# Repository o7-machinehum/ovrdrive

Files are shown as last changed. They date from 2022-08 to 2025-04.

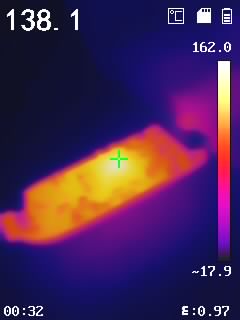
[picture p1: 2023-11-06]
testing/thermal/19700101/IMG000017.jpeg

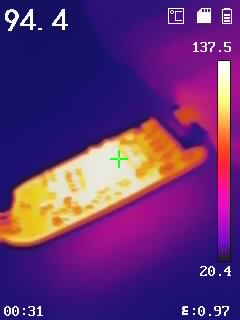
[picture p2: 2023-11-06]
testing/thermal/19700101/IMG000016.jpeg

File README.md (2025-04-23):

# Ovrdrive


Ovrdrive is a purpose built security focused usb drive. If the user doesn't plug it in three times rapidly, the drive it will appear completely blank. It is entirely open source and all the tools used to build it are open source. 

## Getting this Code
I've added quite a bit of git lfs content, I will eventually remove all this, but for now you probably don't want to check this out. You can do so like this

    GIT_LFS_SKIP_SMUDGE=1 git clone git@github.com:o7-machinehum/ovrdrive.git

## Content
 - [Blog Post](https://interruptlabs.ca/2022/07/29/I-m-Building-a-Self-Destructing-USB-Drive/)
 - [YouTube Content](https://youtu.be/Wrcy6ySjSu8)
 - [Buy in my Shop](https://shop.rootkitlabs.com/products/ovrdrive-usb)

## Firmware
```
cd fw
make deploy
```

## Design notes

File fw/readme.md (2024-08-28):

# Overdrive Firmware
The firmware consists of just one source file and a header `ovrdrive.c` and `ovrdrive.h`. The hardware is an ATmega25 programmed from a TC2030 programming pad (J3). I have tested that it's possible to use a 1mm pitch, 2x3 header by just holding it down to the pads for a quick and dirty program.

## Software Requirements
```
make
avr-gcc
avrdude
```

## Building
```
make
```

## Flashing
To flash you need an AVR ISP programmer (or an Arduino in ISP mode). 
```
make fuse
make flash
```
In the `rel` folder you will find the `ovrdrive_r1.elf` which is the firmware that was shipped with the device. You can flash this with the `make deploy`

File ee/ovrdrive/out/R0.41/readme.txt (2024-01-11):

Ovrdrive
--------
Size :	36.6 x 15 mm
Layer : 4 Layers
Material : FR-4: TG150
Thickness : 0.6 mm
Min track/spacing : 4/4mil
Min hole size : 0.2mm
Solder mask : Black
Silkscreen : White
Edge connector : No
Surface finish : HASL lead free
Via process : Tenting vias
Finished copper : 1 oz Cu (Inner Copper:1 oz)
Remove product No. : Yes

Update From R0.4
----------------
1) Changed board outline to be more snug in enclosure
2) Added CE logo
3) C3/C14 -> 1uF to 10uF
    - Shouldn't have to plug in / out as fast
4) R5 -> 22R to 0R
    - For heating up better

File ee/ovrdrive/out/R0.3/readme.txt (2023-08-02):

Ovrdrive
--------

Thickness : 0.6 mm
Min hole size : 0.2mm

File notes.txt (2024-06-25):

# Notes

# Final TODO
    - [ ] Extend board for a nicer fit
    - [ ] Increase charge caps capacitance
    - [ ] Replace programming port with TC2030

# Boards (V2)
    1) Hacked to try to make flash work. Probably NFG.
    2) Replaced flash to K9GAG08U0E. Removed: Q2 and C1. Not enumerating through dmesg.
    3) Populated with MT29F64G08CBABAWP
        - Works!
    4-7) Not touched
    8) Poached IC
    9) Not touched
    10) Sent to Crowdsupply

# Boards (V3)
    1) Replaced IC to SM3257ENQBA. Works! Accidentally wired flash backwards.
        - Used SM3257ENBA-P0816
    2) "Bad Block over setting 0X11"
        - No diodes!
        - Trying Star_SM3257ENAA_SM3261AB_M0531
        - Worked (with SM3257ENAA) This IC is okay!
    3) Not showing up
        - Different flash (didn't have enough)
    4) Not showing up - Gets hot
    5) Worked with Star_SM3257ENAA_SM3261AB_M0531

# Boards (V4)
    - ** Important ** : Make sure Virtualbox USB is set to USB 1.1
    - Used SM3257ENBA-P0816
        - Previsioned all 20, no visible errors.

## Parts
  - ATTINY24A-CCUR  - BGA version
  - ATTINY24-20PU   - DIP version
  - K9gag08u0e-Scb0 - NAND Flash
  - SM3255AA        - What dmesg thinks the chip is
  - SM3257EN        - Part number on the chip
  - SM3257ENAA      - Reported by SMI Mass Production Tool
  - 838-22-004-10-001101

## Notes
```
[machinehum@whitebox Star_SM3257ENAA_N0726]$ find . -iname "SM3257ENAA*.FFW"
./UFD_ALL_ForceFW/SM3257ENAA.FFW
```
This is the "ISP" or firmware, source: https://www.usbdev.ru/articles/a_smi/ispcantbefound/

## SMI Mass QC tool
Settings Password: 320
Debug Password: 1111

## Links and Notes
  - [Russian Site 1](https://www.usbdev.ru/articles/testmod/)
  - [Russian Site 2](https://www.usbdev.ru/files/smi/)
  - [SMI MP Tool](https://www.usbdev.ru/files/smi/smimptool/)
  - [Notes on Flash](https://www.elinfor.com/knowledge/practical-guide-for-flash-memory-p-10889)
  - [SMI MP Tool 2](https://flashboot.ru/files/file/243/)
  - [ST's Part](https://www.st.com/en/microcontrollers-microprocessors/st72681.html)

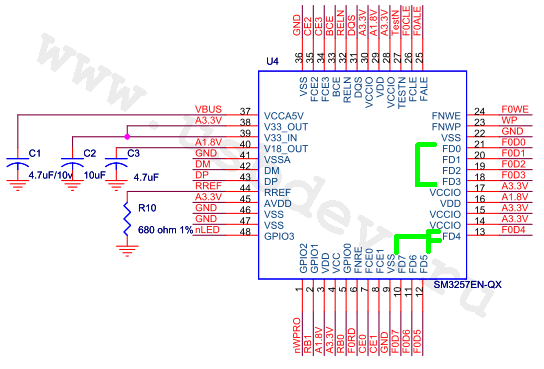
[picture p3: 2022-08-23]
ee/datasheets/SM3257-design.gif

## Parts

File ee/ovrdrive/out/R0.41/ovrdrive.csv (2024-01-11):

Source: | /Users/machinehum/projects/ovrdrive/ee/ovrdrive/ovrdrive.kicad_sch
Date: | 2024 January 11, Thursday 13:58:31
Tool: | Eeschema 7.0.7
Generator: | /opt/homebrew/bin/kicad-vault
Component Count: | 39
Ref | Qnty | Value | Footprint | Part Number | Detailed Description
C1, C15, C16, C18, | 4 | 100nF | Capacitor_SMD:C_0603_1608Metric | CC0603KRX7R7BB104 | 0.1 µF ±10% 16V Ceramic Capacitor X7R 0603 (1608 Metric)
C2, C4, C8, C9, C10, C11, C12, C13, C17, | 9 | 1uF | Capacitor_SMD:C_0603_1608Metric | CC0603KRX7R7BB105 | 1 µF ±10% 16V Ceramic Capacitor X7R 0603 (1608 Metric)
C3, C14, | 2 | 10uF | Capacitor_SMD:C_0603_1608Metric | CL10A106MQ8NNNC | 10 µF ±20% 6.3V Ceramic Capacitor X5R 0603 (1608 Metric)
C5, C6, C7, | 3 | 4.7uF | Capacitor_SMD:C_0603_1608Metric | CL10A475KP8NNNC | 4.7 µF ±10% 10V Ceramic Capacitor X5R 0603 (1608 Metric)
D1, | 1 | LED | LED_SMD:LED_0603_1608Metric | XZMG53W-1 | Green 568nm LED Indication - Discrete 2.2V 0603 (1608 Metric)
D2, D3, | 2 | BAS70LP-7B | Diode_SMD:D_0402_1005Metric | BAS70LP-7B | Diode 70 V 70mA Surface Mount X1-DFN1006-2
J1, | 1 | USB_A | Connector_USB:USB_A_CNCTech_1001-011-01101_Horizontal | 480372200 | USB-A (USB TYPE-A) USB 2.0 Plug Connector 4 Position Surface Mount, Right Angle; Through Hole
R1, R2, | 2 | 1M | Resistor_SMD:R_0402_1005Metric | RC0402FR-071ML | 1 MOhms ±1% 0.063W, 1/16W Chip Resistor 0402 (1005 Metric) Moisture Resistant Thick Film
R3, R4, | 2 | 2.2R | Resistor_SMD:R_0603_1608Metric | RC0603FR-072R2L | 2.2 Ohms ±1% 0.1W, 1/10W Chip Resistor 0603 (1608 Metric) Moisture Resistant Thick Film
R5, | 1 | 0R | Resistor_SMD:R_0603_1608Metric | RC0603FR-070RL | 0 Ohms Jumper Chip Resistor 0603 (1608 Metric) Moisture Resistant Thick Film
R6, | 1 | 1k | Resistor_SMD:R_0603_1608Metric | RC0603FR-071KL | 1 kOhms ±1% 0.1W, 1/10W Chip Resistor 0603 (1608 Metric) Moisture Resistant Thick Film
R7, R8, | 2 | 10k | Resistor_SMD:R_0402_1005Metric | RC0402FR-0710KL | 10 kOhms ±1% 0.063W, 1/16W Chip Resistor 0402 (1005 Metric) Moisture Resistant Thick Film
R9, | 1 | 1k | Resistor_SMD:R_0402_1005Metric | RC0402FR-071KL | 1 kOhms ±1% 0.063W, 1/16W Chip Resistor 0402 (1005 Metric) Moisture Resistant Thick Film
R10, | 1 | 680R | Resistor_SMD:R_0603_1608Metric | RC0603FR-07680RL | 680 Ohms ±1% 0.1W, 1/10W Chip Resistor 0603 (1608 Metric) Moisture Resistant Thick Film
R14, R15, | 2 | 10k | Resistor_SMD:R_0603_1608Metric | RC0402FR-0710KL | 10 kOhms ±1% 0.063W, 1/16W Chip Resistor 0402 (1005 Metric) Moisture Resistant Thick Film
U1, | 1 | SM3257ENT | Package_QFP:TQFP-48_7x7mm_P0.5mm | SM3257ENAA
U2, | 1 | FLASH | TSOP48:tsop48 | MT29F64G08CBABAWP
U3, | 1 | ATtiny24A-MM | Package_DFN_QFN:QFN-20-1EP_3x3mm_P0.45mm_EP1.6x1.6mm | ATTINY24A-MMHR | AVR AVR® ATtiny Microcontroller IC 8-Bit 20MHz 2KB (1K x 16) FLASH 20-VQFN (3x3)
U4, | 1 | SN74LVC1G32DCKR | Package_TO_SOT_SMD:SOT-353_SC-70-5 | SN74LVC1G32DCKR | OR Gate IC 1 Channel SC-70-5
U5, | 1 | DRV8837C | Package_SON:WSON-8-1EP_2x2mm_P0.5mm_EP0.9x1.6mm | DRV8837CDSGR | Motor Driver NMOS PWM 8-WSON (2x2)

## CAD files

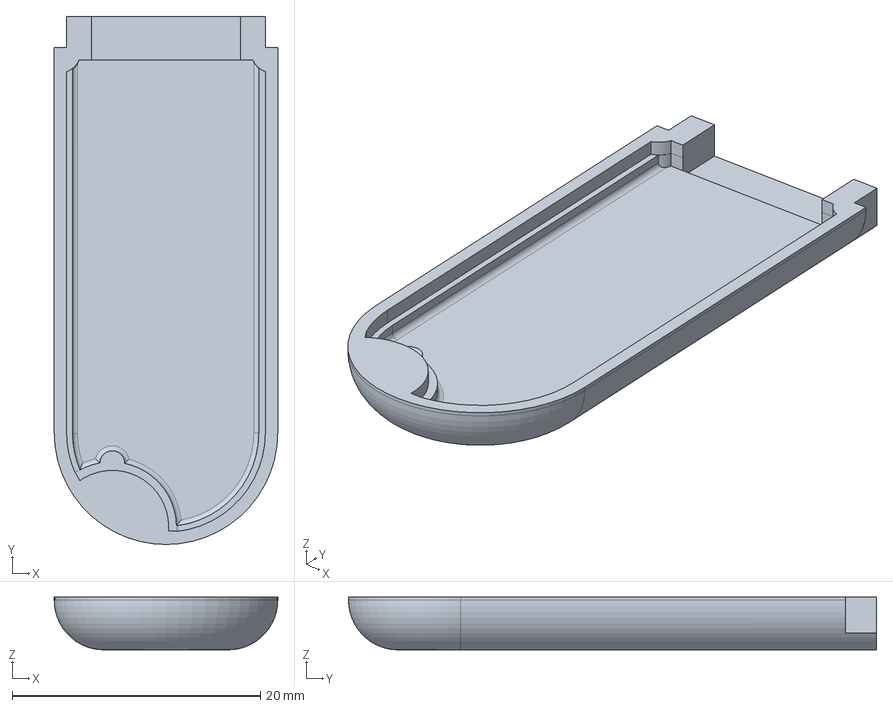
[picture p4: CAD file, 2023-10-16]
mech/case.FCStd
18.0 x 42.5 x 4.25 mm

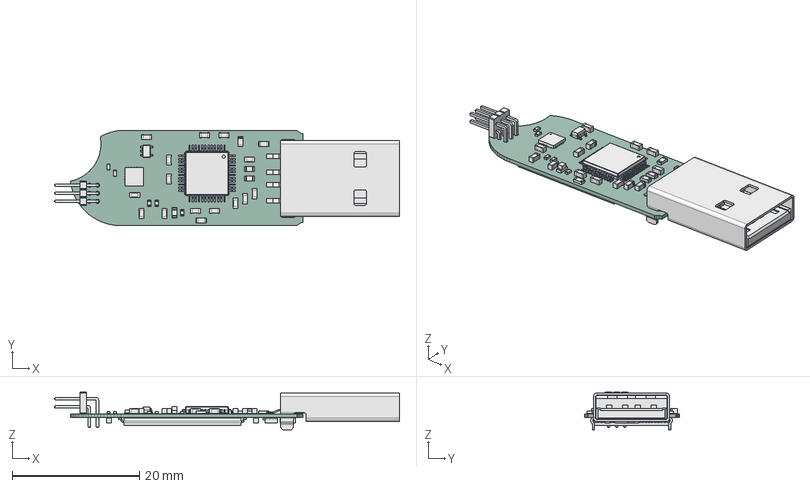
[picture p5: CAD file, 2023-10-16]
mech/pcb.FCStd
54.3 x 15.0 x 5.97 mm
ovrdrive PCB002

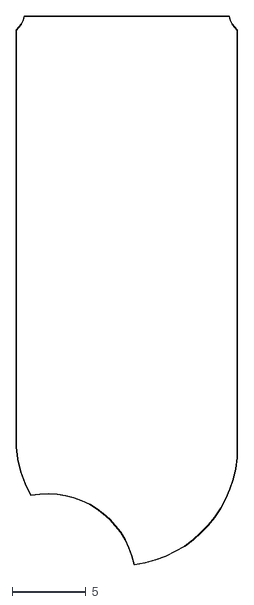
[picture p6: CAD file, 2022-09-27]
mech/outline-ModelSketch.dxf
15.0 x 37.2

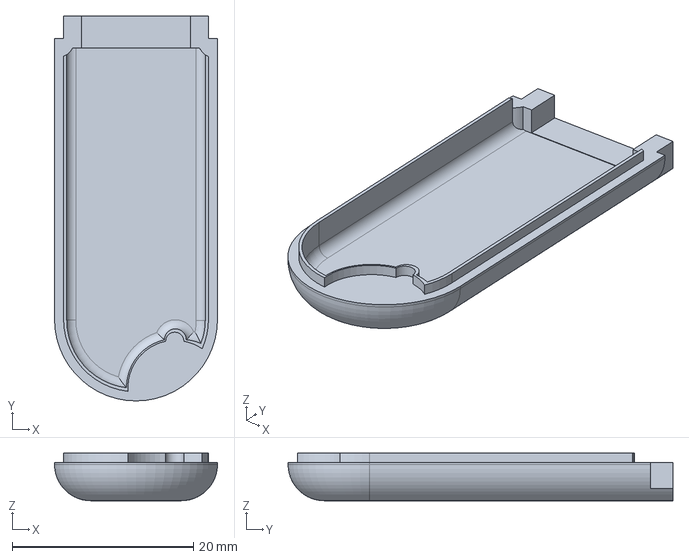
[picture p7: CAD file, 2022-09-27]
mech/case_top.FCStd
18.0 x 42.5 x 5.25 mm

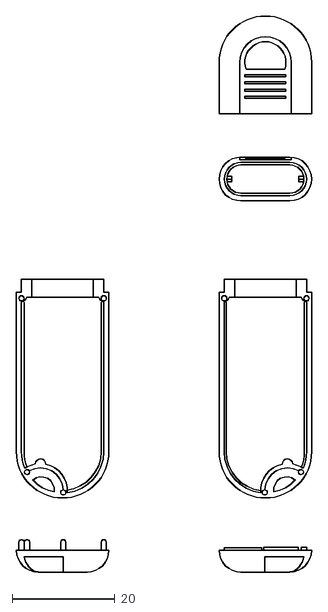
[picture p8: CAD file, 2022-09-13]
mech/LK-USB06.dxf
57.4 x 108.1

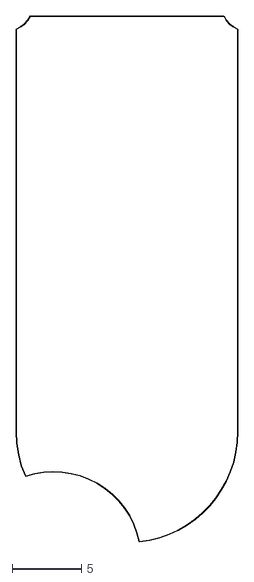
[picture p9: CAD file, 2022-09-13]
mech/LK-USB06_PCB_Outline.dxf
16.0 x 38.0

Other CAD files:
mech/ovrdrive.FCStd
mech/outline.FCStd
mech/LK-USB15.dwg
mech/LK-USB08.dwg
mech/LK-USB09.dwg
mech/LK-USB05.dwg
mech/LK-USB10.dwg
mech/LK-USB06.dwg

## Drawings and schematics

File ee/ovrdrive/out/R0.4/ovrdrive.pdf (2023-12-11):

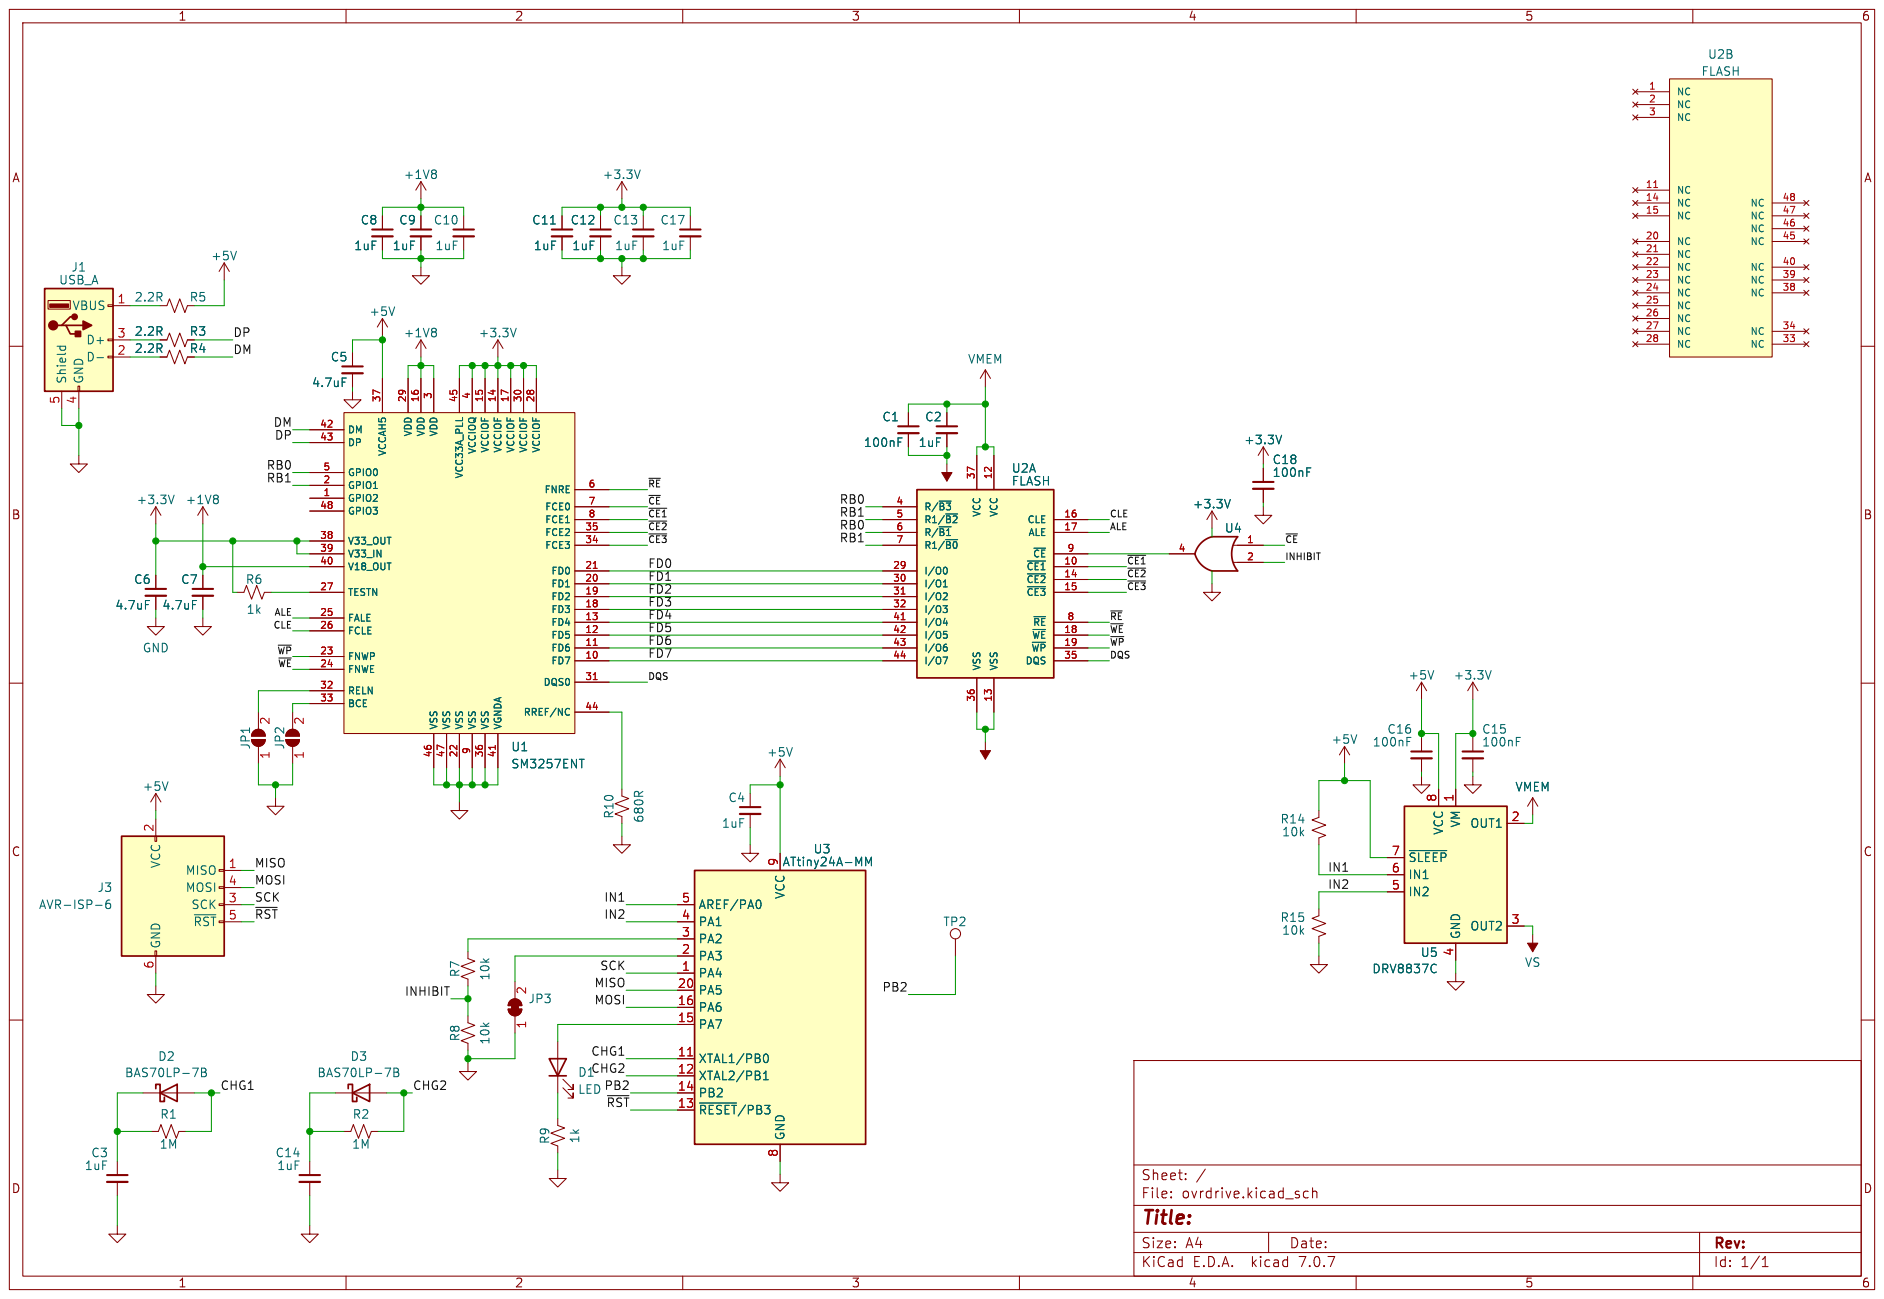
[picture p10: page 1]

3 VCCIOF 30 DQS0 31 RELN 32 BCE 33 FCE3 34 FCE2 35 VSS 36 VCCAH5 37 V33_OUT 38 V33_IN 39 VCCIOQ

4 V18_OUT 40 VGNDA 41 DM 42 DP 43 RREF/NC 44 VCC33A_PLL 45 VSS 46 VSS 47 GPIO3 48 GPIO0 5 FNRE 6 FCE0 7 FCE1 8 VSS

9 U1SM3257ENT GPIO2 1 FD7 10 FD6 11 FD5 12 FD4 13 VCCIOF 14 VCCIOF 15 VDD 16 VCCIOF 17 FD3 18 FD2 19 GPIO1 2 FD1 20 FD0 21 VSS 22 FNWP 23 FNWE 24 FALE 25 FCLE 26 TESTN 27 VCCIOF 28 VDD 29 VDD

~{WE} ~{RE} ~{WP} DQS

2 SCK 3 MOSI 4 ~{RST}5 GND

Id: 1/1 Title: File: ovrdrive.kicad_sch Sheet: /

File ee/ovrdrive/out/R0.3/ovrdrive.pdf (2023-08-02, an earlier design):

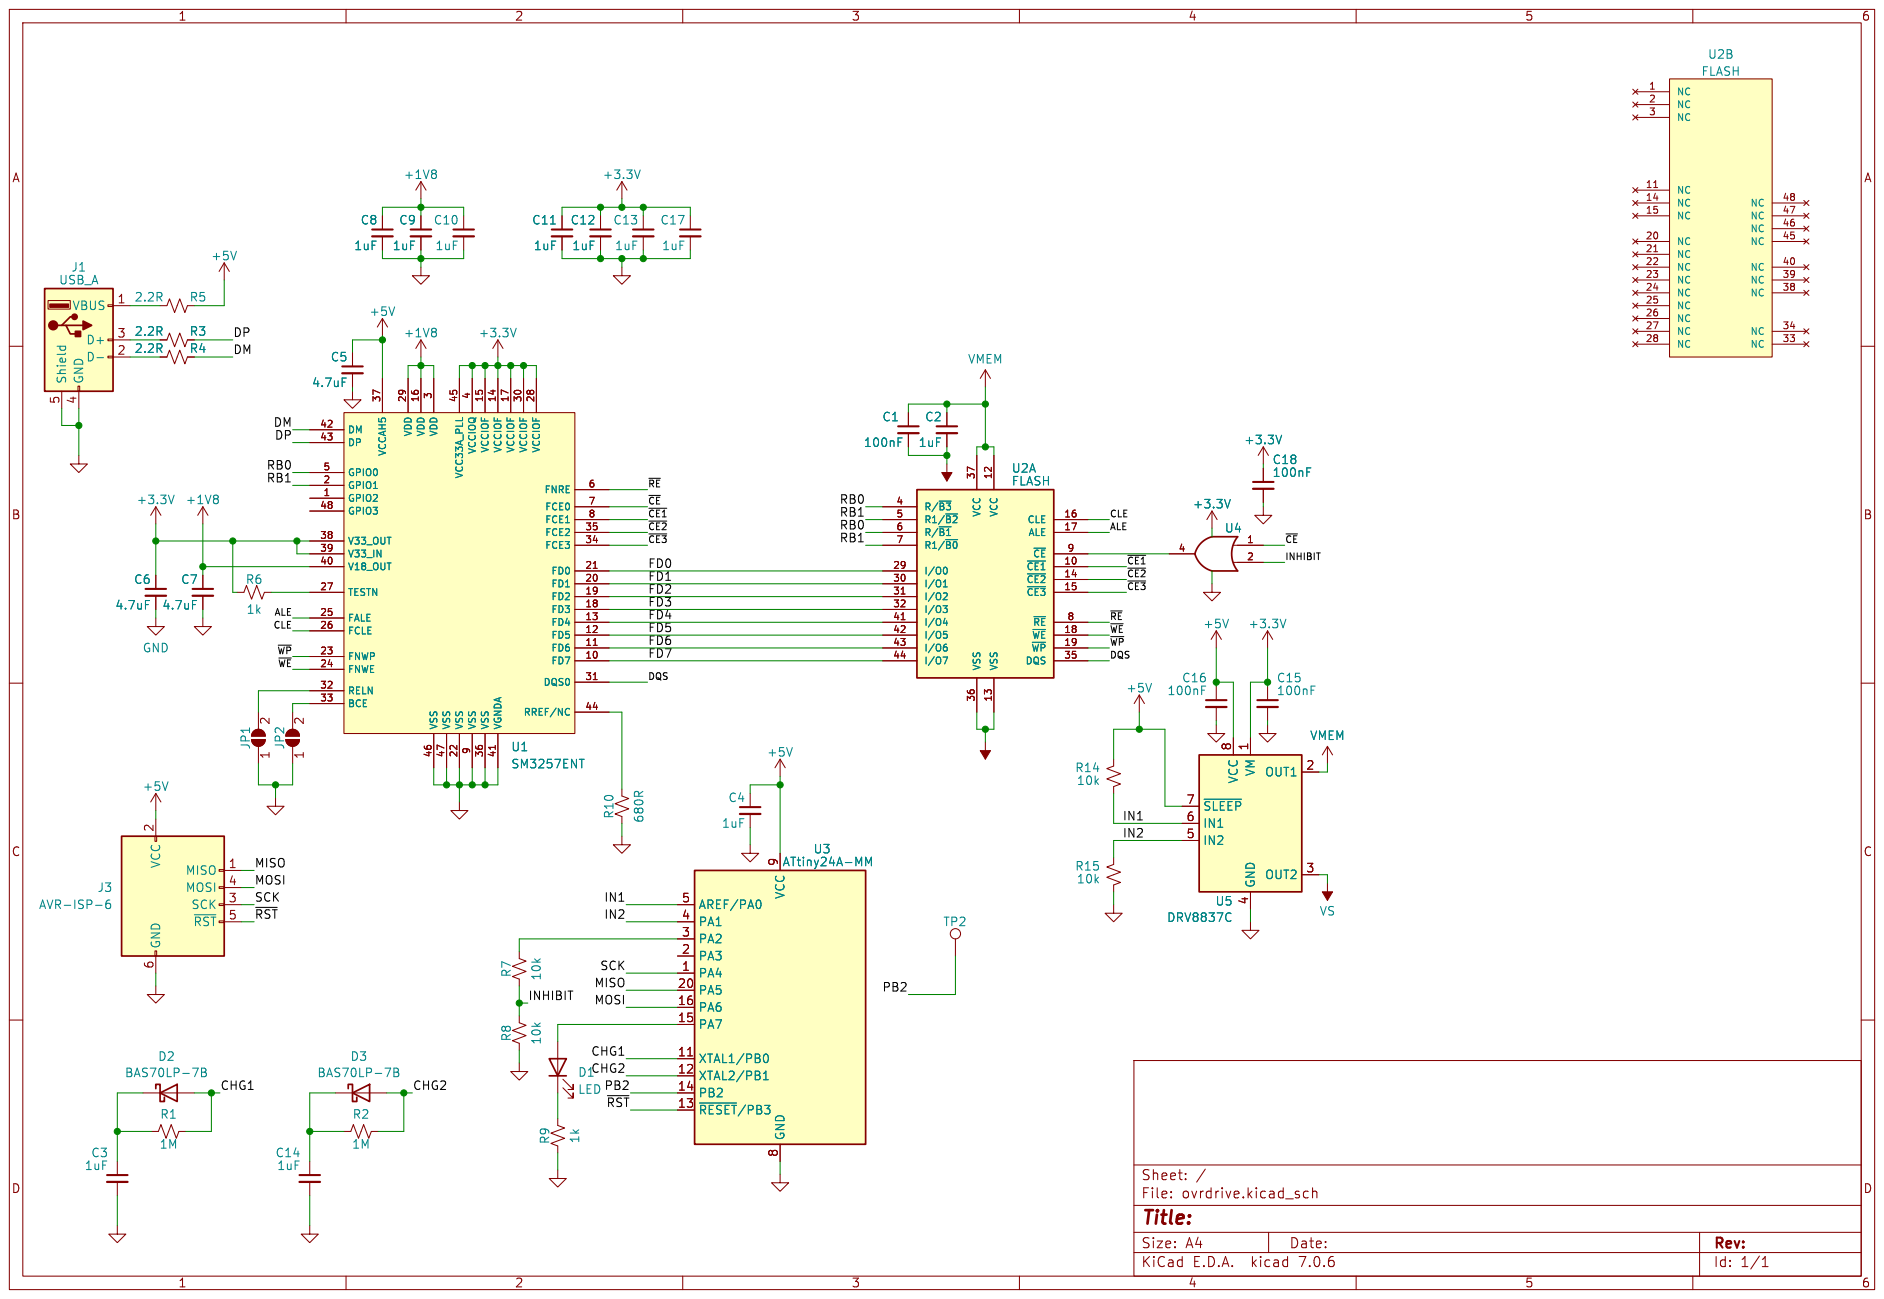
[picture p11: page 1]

Id: 1/1 Title: File: ovrdrive.kicad_sch Sheet: /

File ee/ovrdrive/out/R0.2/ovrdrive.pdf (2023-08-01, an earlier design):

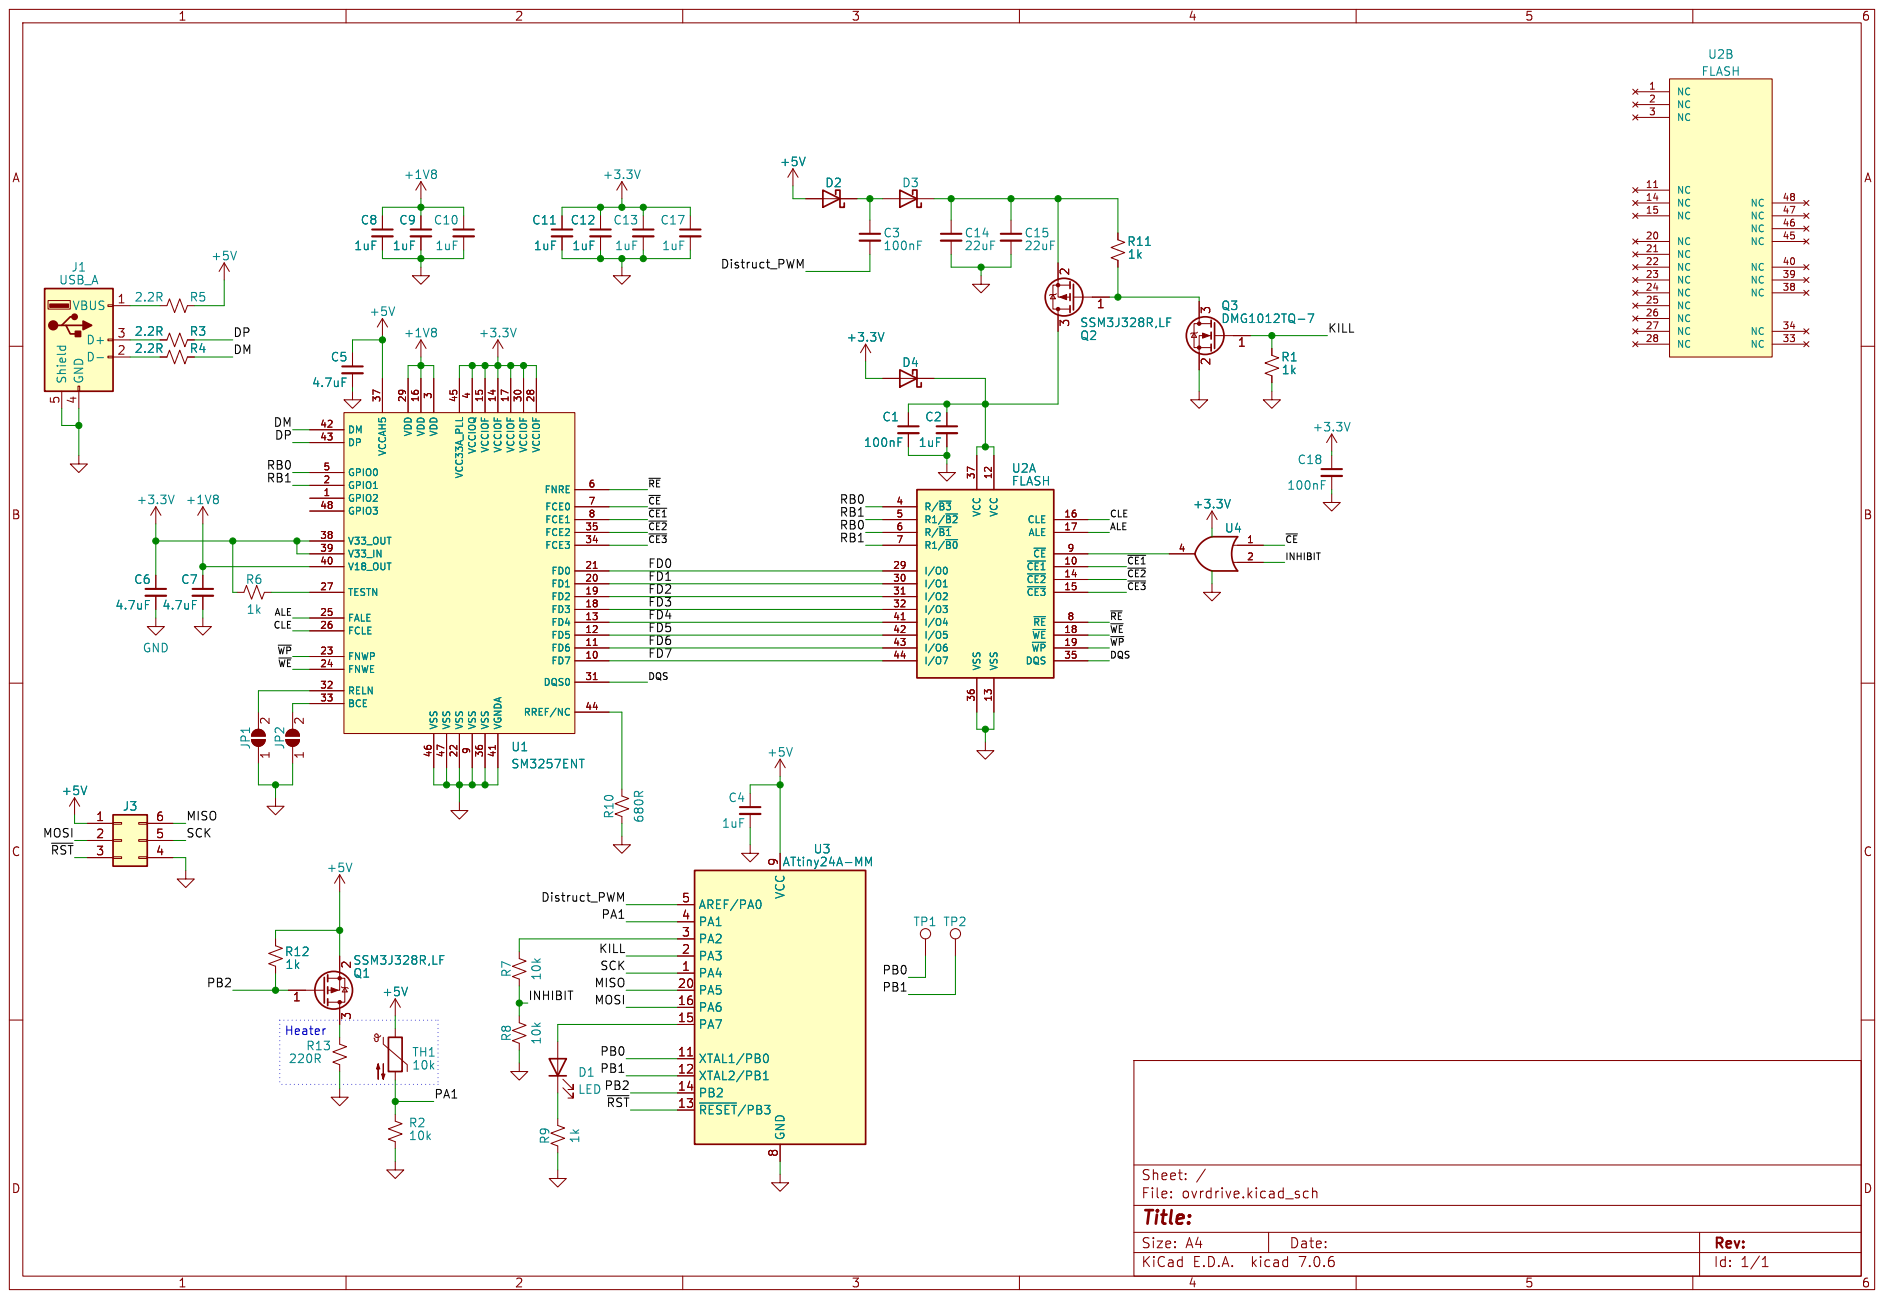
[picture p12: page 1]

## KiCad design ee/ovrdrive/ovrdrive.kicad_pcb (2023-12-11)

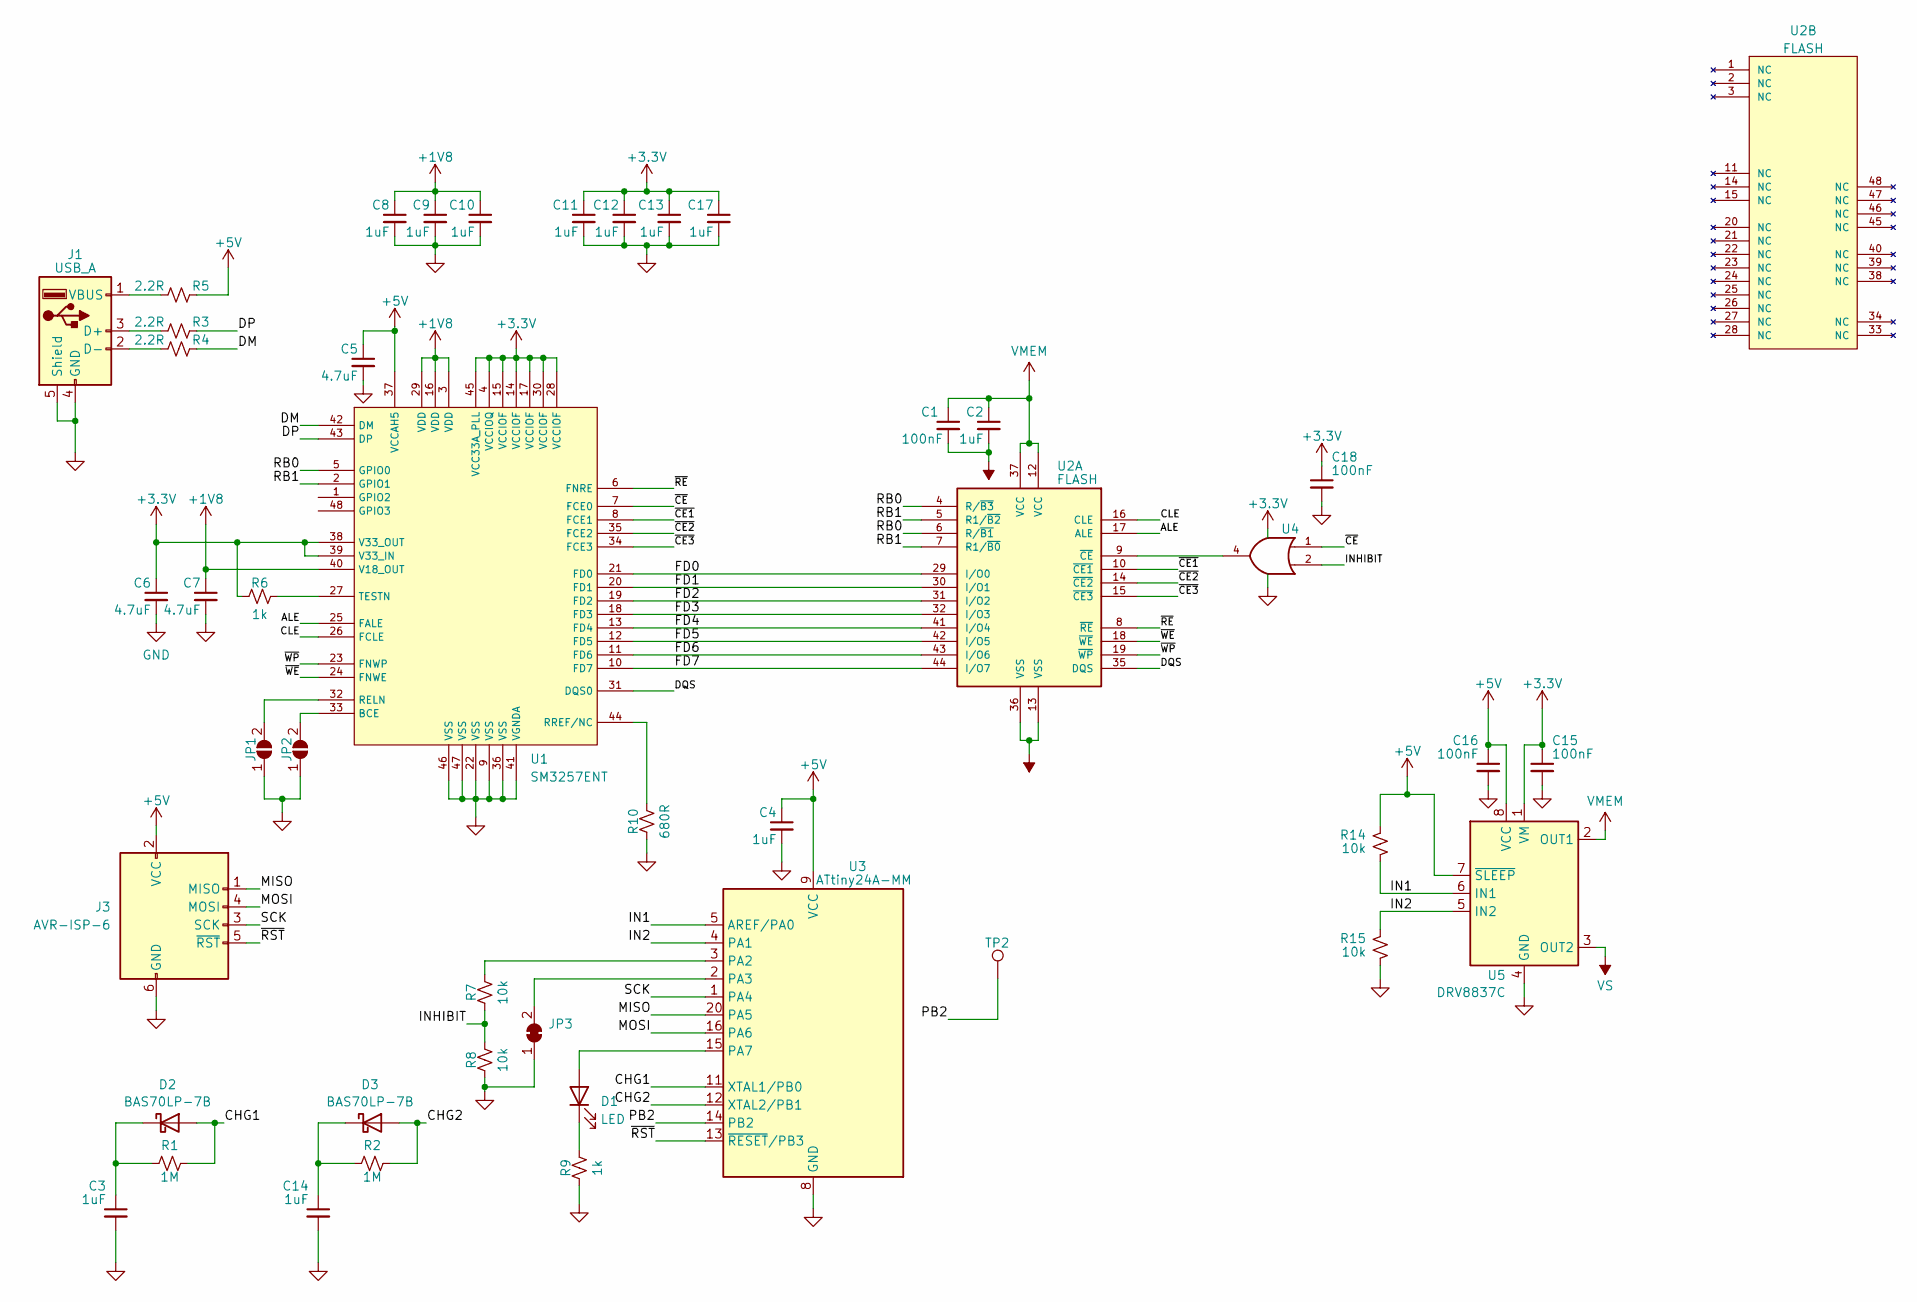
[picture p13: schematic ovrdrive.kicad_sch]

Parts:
C1, C15, C16, C18: 100nF; C_0603_1608Metric; MPN CC0603KRX7R7BB104
C2, C4, C8, C9, C10, C11, C12, C13, C17: 1uF; C_0603_1608Metric; MPN CC0603KRX7R7BB105
C3, C14: 1uF; C_0603_1608Metric
C5, C6, C7: 4.7uF; C_0603_1608Metric; MPN CL10A475KP8NNNC
D1: LED; LED_0603_1608Metric; MPN XZMG53W-1
D2, D3: BAS70LP-7B; D_0402_1005Metric; MPN BAS70LP-7B
J1: USB_A; USB_A_CNCTech_1001-011-01101_Horizontal; MPN 0480372200
J3: AVR-ISP-6; PinHeader_2x03_P1.27mm_Horizontal; MPN 20021112-00006T4LF
JP1, JP2: SolderJumper_2_Open; SolderJumper-2_P1.3mm_Open_Pad1.0x1.5mm
JP3: SolderJumper_2_Bridged; SolderJumper-2_P1.3mm_Bridged2Bar_RoundedPad1.0x1.5mm
R1, R2: 1M; R_0402_1005Metric; MPN RC0402FR-071ML
R3, R4, R5: 2.2R; R_0603_1608Metric; MPN RC0603FR-072R2L
R6: 1k; R_0603_1608Metric; MPN RC0603FR-071KL
R7, R8: 10k; R_0402_1005Metric; MPN RC0402FR-0710KL
R9: 1k; R_0402_1005Metric; MPN RC0402FR-071KL
R10: 680R; R_0603_1608Metric; MPN RC0603FR-07680RL
R14, R15: 10k; R_0603_1608Metric; MPN RC0402FR-0710KL
TP2: TestPoint; TestPoint_Pad_D1.0mm
U1: SM3257ENT; TQFP-48_7x7mm_P0.5mm; MPN SM3257ENT
U2: FLASH; tsop48; MPN K9HDG08U1A
U3: ATtiny24A-MM; QFN-20-1EP_3x3mm_P0.45mm_EP1.6x1.6mm; MPN ATTINY24A-MMHR
U4: SN74LVC1G32DCKR; SOT-353_SC-70-5; MPN SN74LVC1G32DCKR
U5: DRV8837C; WSON-8-1EP_2x2mm_P0.5mm_EP0.9x1.6mm; MPN DRV8837CDSGR

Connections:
+1V8: C7.1, C8.1, C9.1, C10.1, U1.3 (VDD), U1.16 (VDD), U1.29 (VDD), U1.40 (V18_OUT)
+3.3V: C6.1, C11.1, C12.1, C13.1, C15.1, C17.1, C18.1, R6.1, U1.4 (VCCIOQ), U1.14 (VCCIOF), U1.15 (VCCIOF), U1.17 (VCCIOF), U1.28 (VCCIOF), U1.30 (VCCIOF), U1.38 (V33_OUT), U1.39 (V33_IN), U1.45 (VCC33A_PLL), U4.5 (VCC), U5.1 (VM)
+5V: C4.1, C5.1, C16.1, J3.2 (VCC), R5.2, R14.2, U1.37 (VCCAH5), U3.9 (VCC), U5.7 (~SLEEP), U5.8 (VCC)
/ALE: U1.25 (FALE), U2.17 (ALE)
/CHG1: D2.2 (A), R1.1, U3.11 (XTAL1/PB0)
/CHG2: D3.2 (A), R2.1, U3.12 (XTAL2/PB1)
/CLE: U1.26 (FCLE), U2.16 (CLE)
/DM: R4.2, U1.42 (DM)
/DP: R3.2, U1.43 (DP)
/DQS: U1.31 (DQS0), U2.35 (DQS)
/FD0: U1.21 (FD0), U2.29 (I/O0)
/FD1: U1.20 (FD1), U2.30 (I/O1)
/FD2: U1.19 (FD2), U2.31 (I/O2)
/FD3: U1.18 (FD3), U2.32 (I/O3)
/FD4: U1.13 (FD4), U2.41 (I/O4)
/FD5: U1.12 (FD5), U2.42 (I/O5)
/FD6: U1.11 (FD6), U2.43 (I/O6)
/FD7: U1.10 (FD7), U2.44 (I/O7)
/IN1: R14.1, U3.5 (AREF/PA0), U5.6 (IN1)
/IN2: R15.2, U3.4 (PA1), U5.5 (IN2)
/INHIBIT: R7.1, R8.2, U4.2
/MISO: J3.1 (MISO), U3.20 (PA5)
/MOSI: J3.4 (MOSI), U3.16 (PA6)
/PB2: TP2.1, U3.14 (PB2)
/RB0: U1.5 (GPIO0), U2.4 (R/~B3), U2.6 (R/~B1)
/RB1: U1.2 (GPIO1), U2.5 (R1/~B2), U2.7 (R1/~B0)
/SCK: J3.3 (SCK), U3.1 (PA4)
/~CE1: U1.8 (FCE1), U2.10 (~CE1)
/~CE2: U1.35 (FCE2), U2.14 (~CE2)
/~CE3: U1.34 (FCE3), U2.15 (~CE3)
/~CE: U1.7 (FCE0), U4.1
/~RE: U1.6 (FNRE), U2.8 (~RE)
/~RST: J3.5 (~RST), U3.13 (~RESET/PB3)
/~WE: U1.24 (FNWE), U2.18 (~WE)
/~WP: U1.23 (FNWP), U2.19 (~WP)
GND: C3.2, C4.2, C5.2, C6.2, C7.2, C8.2, C9.2, C10.2, C11.2, C12.2, C13.2, C14.2, C15.2, C16.2, C17.2, C18.2, J1.4 (GND), J1.5 (Shield), J3.6 (GND), JP1.1 (A), JP2.1 (A), JP3.1 (A), R8.1, R9.1, R10.1, R15.1, U1.9 (VSS), U1.22 (VSS), U1.36 (VSS), U1.41 (VGNDA), U1.46 (VSS), U1.47 (VSS), U3.8 (GND), U3.21 (GND), U4.3 (GND), U5.4 (GND), U5.9 (GND)
unnamed: D1.2 (A), U3.15 (PA7)
unnamed: D1.1 (K), R9.2
unnamed: C3.1, D2.1 (K), R1.2
unnamed: C14.1, D3.1 (K), R2.2
unnamed: J1.3 (D+), R3.1
unnamed: J1.2 (D-), R4.1
unnamed: J1.1 (VBUS), R5.1
unnamed: JP1.2 (B), U1.32 (RELN)
unnamed: JP2.2 (B), U1.33 (BCE)
unnamed: JP3.2 (B), U3.2 (PA3)
unnamed: R10.2, U1.44 (RREF/NC)
unnamed: R6.2, U1.27 (TESTN)
unnamed: U2.9 (~CE), U4.4
unnamed: R7.2, U3.3 (PA2)
VMEM: C1.1, C2.1, U2.12 (VCC), U2.37 (VCC), U5.2 (OUT1)
VS: C1.2, C2.2, U2.13 (VSS), U2.36 (VSS), U5.3 (OUT2)

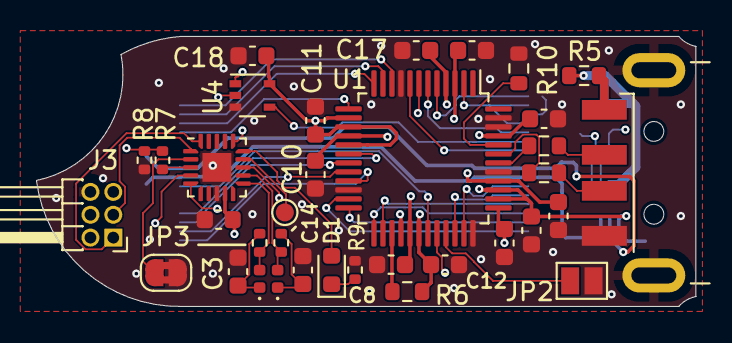
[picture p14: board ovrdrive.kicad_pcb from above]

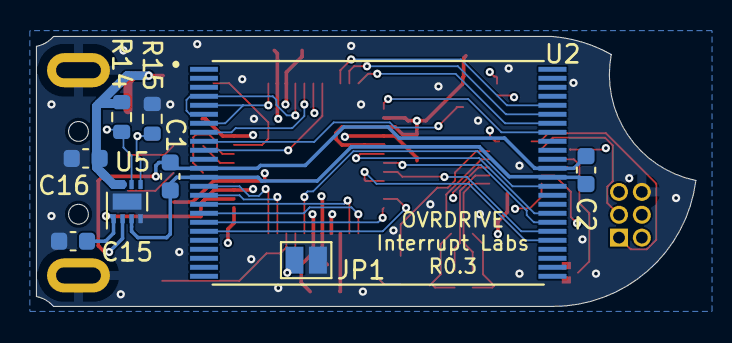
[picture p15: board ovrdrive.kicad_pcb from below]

Board: 4 copper layers, 36.6 x 15.0 mm, 44 parts (9 on the bottom side), 52 nets.

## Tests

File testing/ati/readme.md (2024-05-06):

# Automated Testing Infrastructure
This is a simple suite to test the drives as mass scale.

``` bash
python /dev/sd5 /dev/sd6 /dev/sd6
```

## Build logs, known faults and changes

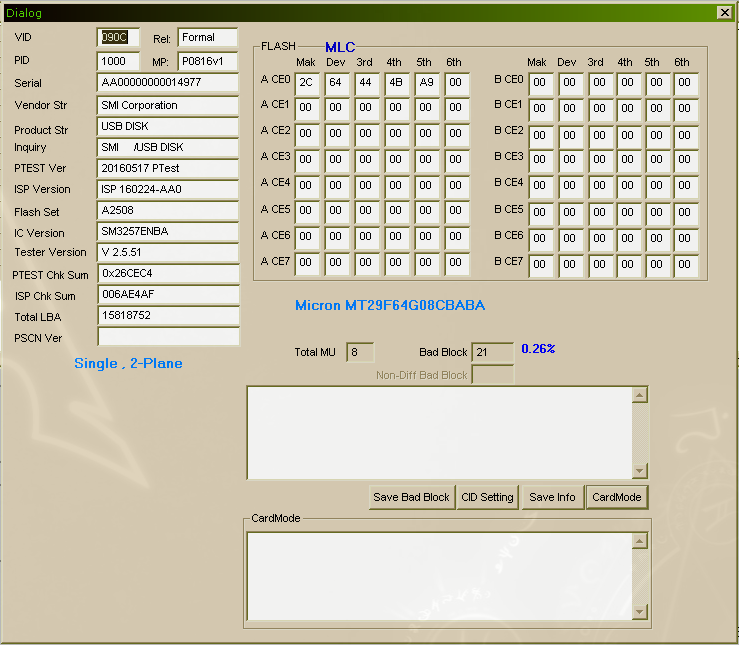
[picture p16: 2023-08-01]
config/debug.png

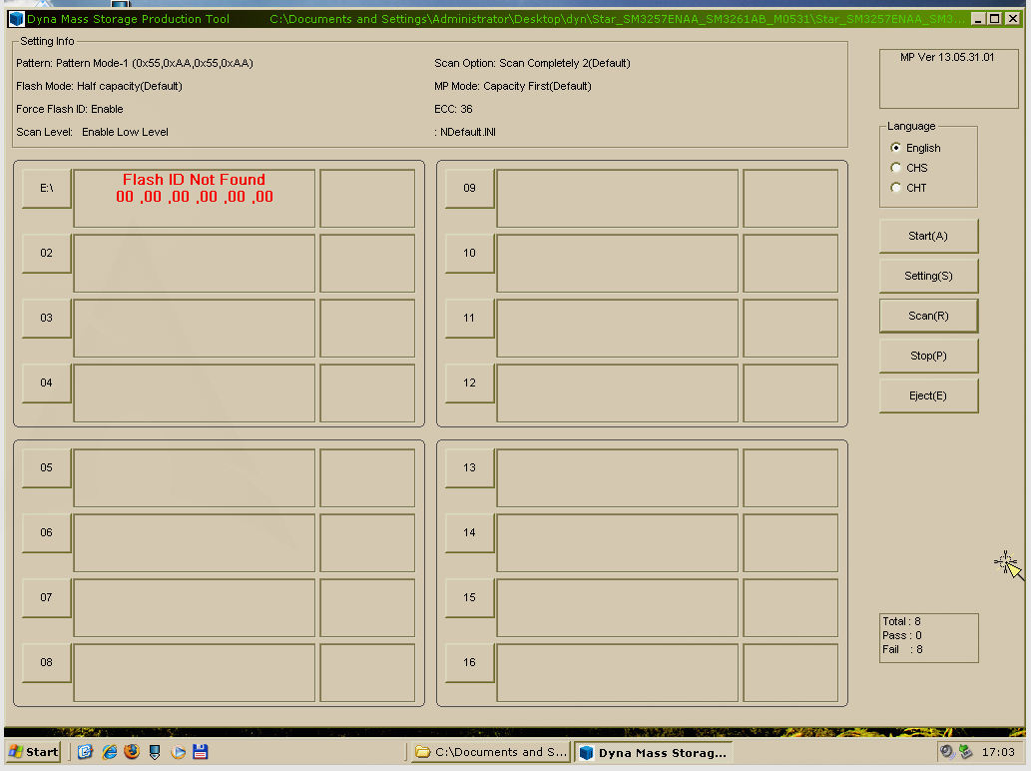
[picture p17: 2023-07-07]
ee/debug-v2/no-flash.png

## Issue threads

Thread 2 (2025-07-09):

Just trying to help

SoLongSidekick, 2025-07-09:
Not an actual issue, but you don't mention anywhere on the store page or here what size storage the device offers - or any other stats of the device. Feel free to close this issue once you see it.

Closed 2025-07-09.

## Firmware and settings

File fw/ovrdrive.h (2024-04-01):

/* Production Variables */
#define SAFE false // Don't ARM FSD cct. ?

/* IN1 / IN2 DRV8837C */
#define PIN_IN1 PA0
#define DDR_IN1 DDRA
#define PORT_IN1 PORTA
#define PIN_IN2 PA1
#define DDR_IN2 DDRA
#define PORT_IN2 PORTA

/* Flash Inhibit Signal */
#define PIN_INHIBIT PA2
#define DDR_INHIBIT DDRA
#define PORT_INHIBIT PORTA

/* LED */
#define PIN_LED PA7
#define DDR_LED DDRA
#define PORT_LED PORTA

/* Charge Pins*/
#define PIN_CHG1 PB0
#define PIN_CHG2 PB1
#define DDR_CHG DDRB
#define PORT_CHG PORTB
#define PORT_I_CHG PINB

/* Full Self Destruct Select */
#define PIN_FSD PA3
#define DDR_FSD DDRA
#define PORT_FSD PORTA
#define PORT_I_FSD PINA

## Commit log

2020-08-28 Updated the pitch deck
2020-09-01 Worked on the pitch
2022-07-19 Dropped the hardware in the initial project.
    [ovrdrive.kicad_pcb, ovrdrive.kicad_sch]
2022-07-20 Working on the board.
    [ovrdrive.kicad_pcb, ovrdrive.kicad_sch]
2022-08-16 Updated the sm3257en to the correct pinout. Dropped some parts on the layout.
    [ovrdrive.kicad_pcb, ovrdrive.kicad_sch]
2022-08-23 Added design guides.
    [ovrdrive.kicad_sch]
2022-09-13 Added a bunch of mech parts.
    [LK-USB05.dwg, LK-USB06.dwg, LK-USB06.dxf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]
2022-09-13 Mech looking decent, new USB to fit in case.
    [case.FCStd, ovrdrive.FCStd, ovrdrive.kicad_pcb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]
2022-09-27 Fit seems to be working.
    [case.FCStd, case_top.FCStd, outline.FCStd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]
2022-09-27 Added a dxf I forgot
    [outline-ModelSketch.dxf]
2022-09-28 Routed out the power.
    [ovrdrive.kicad_pcb, ovrdrive.kicad_sch]
2022-09-29 Working on the routing.
    [ovrdrive.kicad_pcb, ovrdrive.kicad_sch]
2022-10-10 Routed out the datalines.
    [ovrdrive.kicad_pcb]
2022-10-18 Initial routing complete.
    [ovrdrive.kicad_pcb, ovrdrive.kicad_sch]
2022-10-18 R0.1 released
    [ovrdrive-B_Cu.gbr, ovrdrive-B_Mask.gbr, ovrdrive-B_Paste.gbr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]
2022-11-26 Added some part numbers.
    [ovrdrive.kicad_sch]
2022-11-26 Moved files to bench folder (breadboard) and ff folder (actual device).
2023-02-17 Added some datasheets made some changes to the boards.
    [ovrdrive.kicad_sch]
2023-03-07 Removed analog circuitry for spit detection, shortened entire board by 0.6mm to fit in enclosure.
    [ovrdrive.kicad_pcb, ovrdrive.kicad_sch]
2023-04-06 Changes components and a leftover commit.
    [ovrdrive.kicad_pcb, ovrdrive.kicad_sch]
2023-05-02 Added R0.2 docs
    [ovrdrive-B_Cu.gbr, ovrdrive-B_Mask.gbr, ovrdrive-B_Paste.gbr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]
2023-08-01 Added config files that are working for the new flash.
    [ovrdrive.kicad_sch]
2023-08-01 Change the destruction circuit to an H-bridge.
    [ovrdrive.kicad_pcb, ovrdrive.kicad_sch]
2023-08-01 Added screen captures of V1 destruction circuit
2023-08-01 Started the routing the new H-bridge.
    [ovrdrive.kicad_pcb, ovrdrive.kicad_sch]
2023-08-02 R0.3 released
    [ovrdrive-B_Cu.gbr, ovrdrive-B_Mask.gbr, ovrdrive-B_Paste.gbr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]
2023-08-02 Updated the mech, added some small dimensions to the pcb.
    [outline.FCStd, ovrdrive.FCStd, ovrdrive.kicad_pcb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]
2023-10-16 Leftover uncommited stuff.
    [case.FCStd, ovrdrive.FCStd, pcb.FCStd]
2023-11-03 Added BOM commmited leftover stuff.
    [ovrdrive.csv, ovrdrive.kicad_sch]
2023-12-06 Added license
    [ovrdrive.kicad_sch]
2023-12-11 Released R0.4 for *quote only*. Still need to do a final revision before sending off.
    [ovrdrive-B_Cu.gbr, ovrdrive-B_Mask.gbr, ovrdrive-B_Paste.gbr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]
2023-12-11 Added new part numbers
    [ovrdrive.kicad_sch]
2024-01-11 R0.41 released.
    [ovrdrive-B_Cu.gbr, ovrdrive-B_Mask.gbr, ovrdrive-B_Paste.gbr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]
2024-04-01 Modified board size to fit enclosure better.
    [ovrdrive.kicad_sch]
2024-04-01 R0.42 released, ready for review.
    [ovrdrive-B_Cu.gbr, ovrdrive-B_Mask.gbr, ovrdrive-B_Paste.gbr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]
2024-05-06 Working (single thread)
2024-06-25 R1 Released! Going to production.
    [ovrdrive-B_Cu.gbr, ovrdrive-B_Mask.gbr, ovrdrive-B_Paste.gbr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]
